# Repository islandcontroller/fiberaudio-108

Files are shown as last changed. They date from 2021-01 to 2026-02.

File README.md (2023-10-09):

# fiberaudio-108

[]()

A low-cost USB audio interface with S/PDIF optical output, based on the Cmedia CM108AH ASIC.

<p align="center"><picture>
  <source media="(prefers-color-scheme: dark)" srcset="doc/block-schem-wh.svg" />
  <source media="(prefers-color-scheme: light)" srcset="doc/block-schem.svg" />
  Block schematic
</picture></p>

View [**Schematic**](doc/sch_fiberaudio-108_rev5.pdf) :page_facing_up: or [**PCB Preview**](https://htmlpreview.github.io/?https://github.com/islandcontroller/fiberaudio-108/blob/master/doc/ibom.html) :globe_with_meridians:. Customize using the [**CM108AH Configuration Tool**](sw/README.md) :cd:.

Production files will be made available on the [Releases](https://github.com/islandcontroller/fiberaudio-108/releases) page, once validation is complete.

### Key features

* Cmedia CM108AH audio interface ASIC
* 2.0 Stereo, up to 16-bit/48kHz (CD-DA equivalent)
* USB Mini-B input
* Optical S/PDIF output (JIS F05, e.g. TOSLINK&trade;)
* USB Audio Device Class 1.0, uses generic drivers
* Configuration EEPROM

## Overview

This USB audio interface provides a low-cost S/PDIF optical output for portable computers and tablet devices. Audio tranmission via optical link - as opposed to a wired line-level connection - eliminates hum caused by ground potential differences, and noise feed-through from switched-mode power supplies.

| Design Requirement | Solution Approach |
|---|---|
| Provide electrical isolation between device and audio equipment | Audio signal transmission via optical link (e.g. TOSLINK&trade;) |
| Compatibility for wide range of operating systems, with minimal driver maintenance | USB Audio Device Class using OS-provided generic drivers |
| IP accessibility for PCB design files | Use of free, open-source EDA tooling (e.g. KiCad) |
| Commonly-used, small form-factor USB connector, robust enough to withstand portable use | USB **mini**-B receptacle |
| Option for manual assembly | Passives no smaller than 0603. ICs leaded and no smaller than 0.5mm pin pitch (SSOP) |
| Low PCB production capability requirements | &bullet;&nbsp;FR4 base material<br/>&bullet;&nbsp;2-layer Cu, Top+Bot Mask, Top Overlay<br/>&bullet;&nbsp;&geq;0.25mm trace-to-outline<br/>&bullet;&nbsp;&geq;0.25mm trace width and spacing<br/>&bullet;&nbsp;&geq;0.35mm drill size<br/>&bullet;&nbsp;Gerber, NC Drill and RS274X outputs |

## Design Review (Prototyping)

Prototyping was carried out using **rev. 3** board design files, in a minimum-order batch of 5 PCBs, including automated assembly.

### Assembly

* Manual rework of the PCB around `U3` (SRV05-4) was required in order to fix the issues found in *rev. 3*, after production was already started.
* Parts `U1` (AT93C46D), `U2` (CM108AH), `SW1`, and both connectors were unavailable for automated assembly, and had to be retrofitted manually using hot-air reflow soldering.

### Software Support

* Drivers included with **SteamOS 3.0** provide full functionality out-of-box, including volume controls for S/PDIF output.

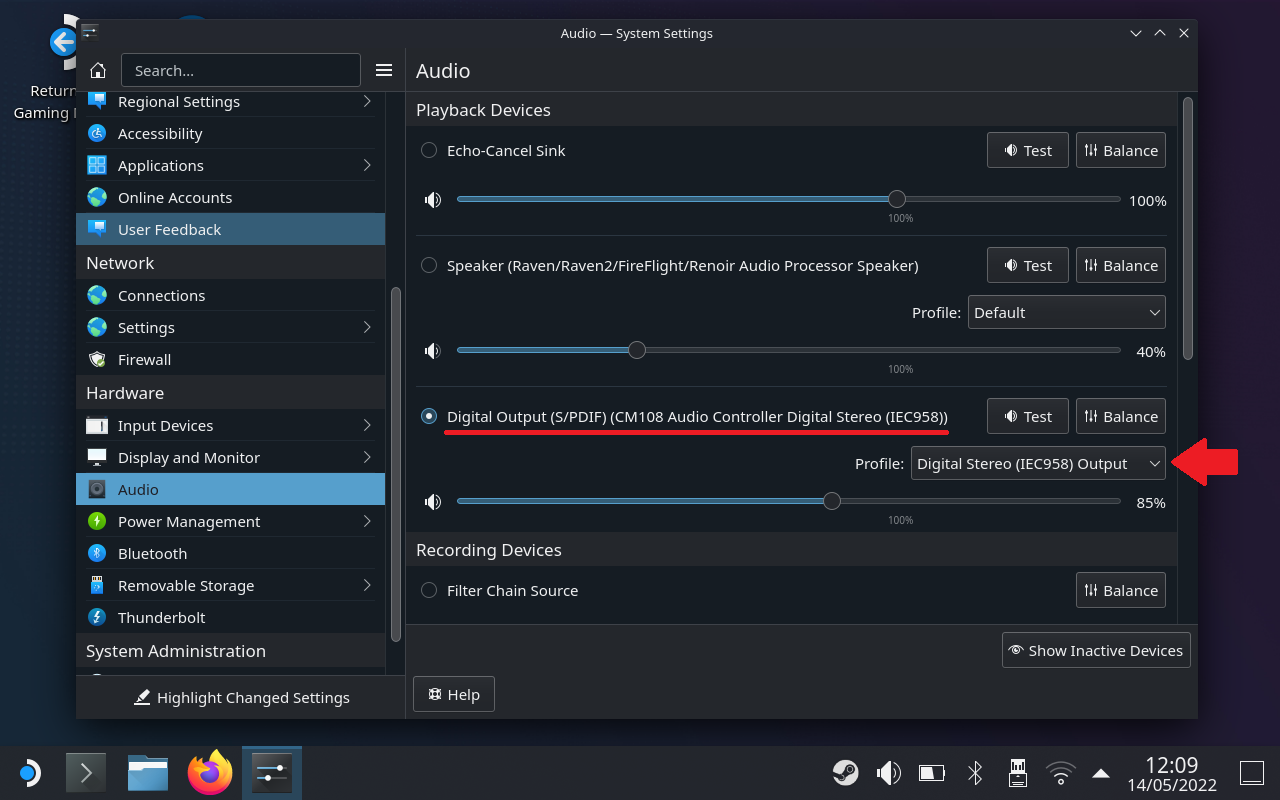
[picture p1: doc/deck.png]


* Generic Audio Device drivers included in **Windows 7.1** (x64) as well as **Windows 10** (Version 22H2, x64) only support S/PDIF output in a passthrough mode. **Volume control and the mute input are inoperative when using the default driver package** (see below for workaround).

**Workaround:** ~~A vendor-specific Windows driver package for the CM108AH is available for download from the ASIC manufacturer's website: [https://www.cmedia.com.tw/support/download_center](https://www.cmedia.com.tw/support/download_center).~~

> Updated 08/2023: *Unfortunately, the ASIC manufacturer have stopped providing any drivers for download. I uploaded the latest signed driver package I could source (Version 8.1.8.2172) as [release `v0.1.5-driver-only`](https://github.com/islandcontroller/fiberaudio-108/releases/tag/v0.1.5-driver-only). Please check the file for integrity and verify it includes the correct signed driver binary before installing.*

~~Using the Windows device manager, perform a manual driver update of the `Generic USB PnP Sound Device`, and select `Win8\SoftwareDriver` from the extracted archive as the driver installation sources directory.~~

> Updated 08/2023: *To install the driver, extract the archive and right-click install the `Cm108.INF` file.*

After installation and a reboot, a new `Digital Audio (USB PnP Sound Device)` device will show up in the Sound Settings dialog, alongside the old `Speakers (USB PnP Sound Device)` device. 

**Disable** the `Speaker` device.

This workaround was tested using Windows 7.1 (x64), and Windows 10 (Version 22H2, x64).

### Device Configuration

* A configuration tool for re-programming the external EEPROM was developed and is provided in the [`sw/`](sw/) subdirectory.

* EEPROM access sporadically seems to return invalid data. Re-reading or re-programming the affected words can be used as a workaround.

### Summary

* The device works correctly in connection with Linux systems. For Windows hosts, a custom driver installation is required for the device to operate properly.

## Licensing

If not stated otherwise within the specific file, the contents of this project are licensed under the CERN Open Hardware Licence Version 2 - Permissive. The full license text is provided in the [`LICENSE`](LICENSE) document.

        SPDX-License-Identifier: CERN-OHL-P-2.0

This licensing model is compliant with the [Open Source Hardware Definition 1.0](https://www.oshwa.org/definition/).

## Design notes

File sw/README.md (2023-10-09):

# CM108AH Configuration Tool

A Python tool for accessing the CM108AH external configuration EEPROM via the ASIC's custom HID endpoint.

## System requirements

* Python 3.8+
* Windows OS (limitation due to PyWinUSB.HID library)

## Installation

1. Create a new virtual environment using:

        python -m venv .venv

2. Activate the virtual environment

        .\.venv\Scripts\activate

3. Install the dependencies using the provided `requirements.txt` file:

        pip install -r requirements.txt

## Usage

Before running this tool, activate the Python virtual environment using:

    .\.venv\Scripts\activate

The tool uses a YAML configuration file to create and download an EEPROM image to the device. A blank configuration template is provided in [`config_template.yaml`](config_template.yaml). The proposed configuration for fiberaudio-108 boards is provided in [`fiberaudio-108.yaml`](fiberaudio-108.yaml).

To display a help message, use:

    python .\cm108ah.py -h

To list all available Cmedia devices, use: (**Note: Not all listed devices may support EEPROM features**)

    python .\cm108ah.py list

To program a configuration from an existing file into the device, use:

    python .\cm108ah.py program <filename>

Each mode command now supports fields for custom Vendor-ID, Product-ID and device index:

    python .\cm108ah.py read --vid 0d8c --pid 013c --device 1

**Retry programming, if the verification step fails.** After programming, the device needs to be power cycled, in order to apply the new configuration.

The tool offers additional options for erasing and reading the configuration EEPROM. See the help message for details.

## Licensing

This tool is part of the [fiberaudio-108](https://github.com/islandcontroller/fiberaudio-108) project. It is licensed under the parent project's conditions.

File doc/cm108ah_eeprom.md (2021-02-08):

# CM108AH EEPROM Access

The Cmedia `CM108` ASIC offers access to the attached EEPROM via an HID endpoint.
## Report data structure

Descriptions for each data byte of the in/out reports are provided in the [datasheet](cm108ah.pdf). For reference, the HID report number `0` needs to be prepended, for a total of 5 bytes per transfer.

## Read/Write access

Read/Write access modes are configured using the `HID_OR3 / EEPROM_CTRL` register. Command encoding differs from `AT93C46` access commands, as shown below.

| `EEPROM_CTRL` Bit | Descriptions |
|---|---|
| [7:6] | Access mode<br/>`0b10`: Read access<br/>`0b11`: Write access |
| [5:0] | Word address A<sub>5</sub>-A<sub>0</sub> |

**Read access mode** will initiate an SPI transfer to the external EEPROM, containing the `READ` command, followed by 16 clocks for the resulting output word.

    > SB (0x80 + addr)    0x00       0x00
    <                  data[15:8] data[7:0]

**Write access mode** will initially transfer an `EWEN` command to the EEPROM, followed by a `WRITE` transfer for 16 data bits. The CM108 will then toggle the clock line until the EEPROM signals a `READY` state.

    > SB 0x30  //  SB (0x40 + addr) data[15:8] data[7:0] 0x00 ... 0x00
    <                                                    BUSY ... READY

**Other access mode values** seem to have no effect, and do not produce any output on the SPI bus.

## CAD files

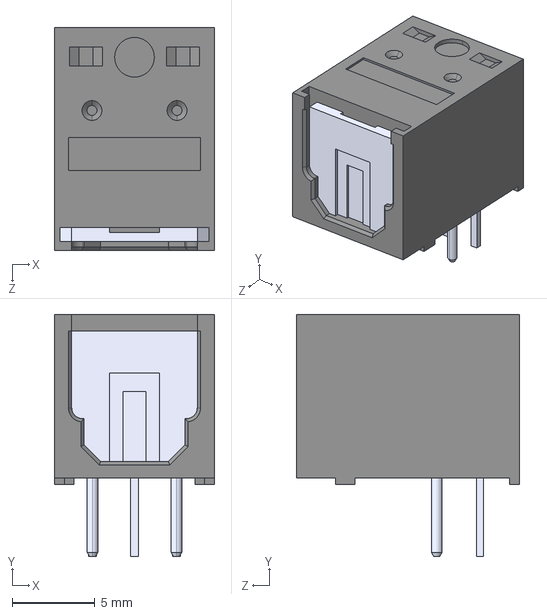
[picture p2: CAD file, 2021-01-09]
doc/plt133_t10w.step
9.70 x 14.7 x 13.5 mm

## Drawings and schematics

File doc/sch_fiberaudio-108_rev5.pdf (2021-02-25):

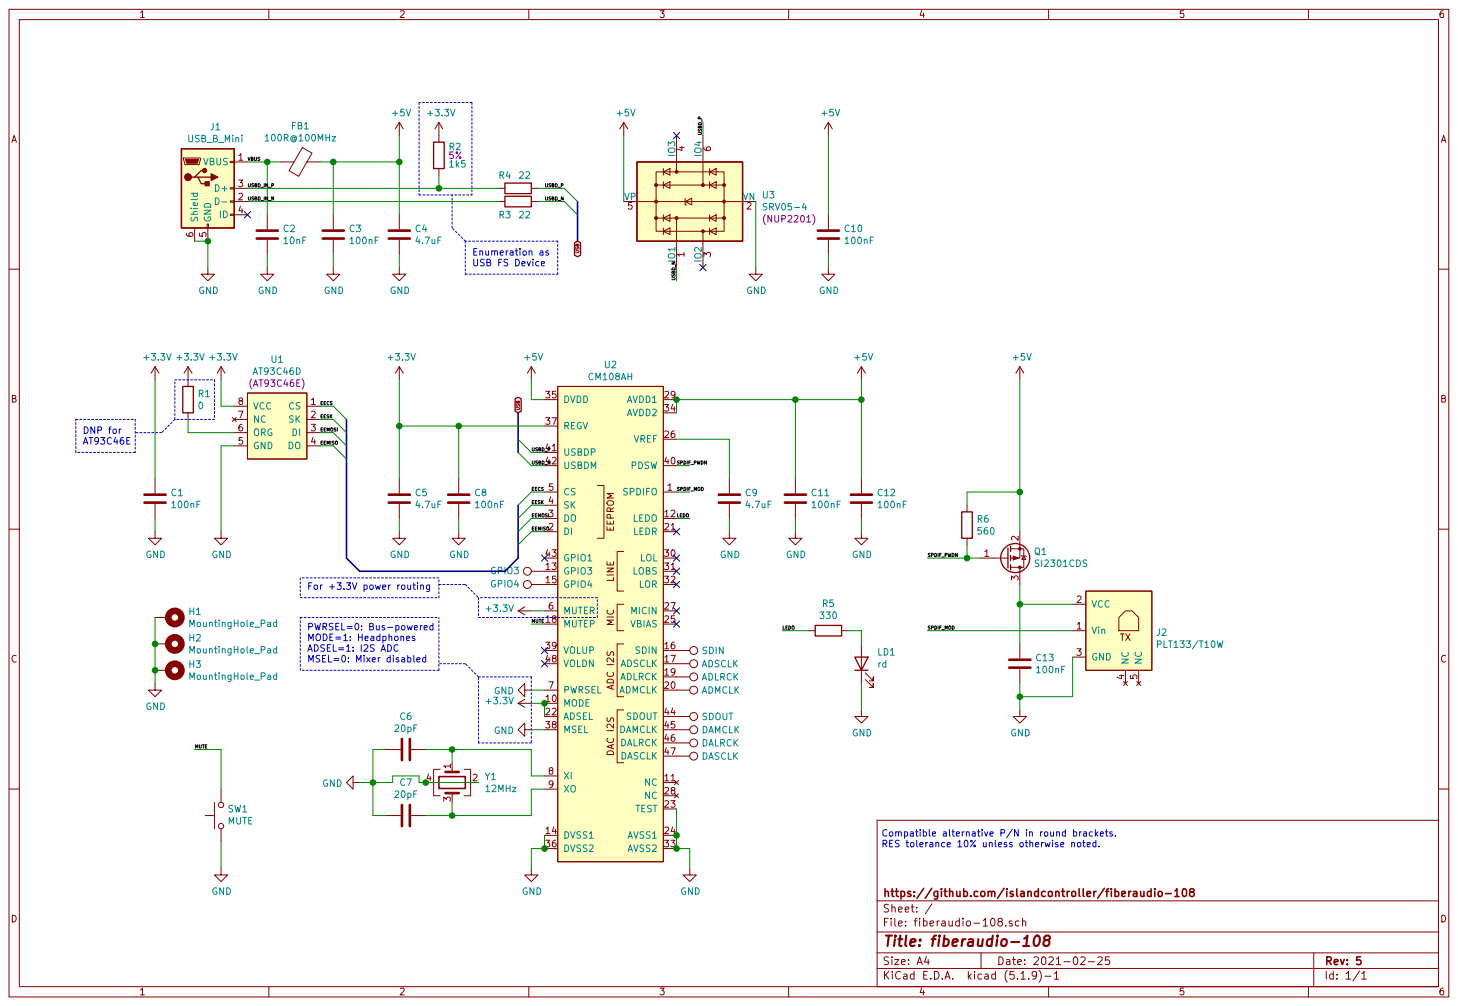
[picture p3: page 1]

MODE=1: Headphones ADSEL=1: I2S ADC MSEL=0: Mixer disabled For +3.3V power routing

File: fiberaudio-108.sch Sheet: / https://github.com/islandcontroller/fiberaudio-108

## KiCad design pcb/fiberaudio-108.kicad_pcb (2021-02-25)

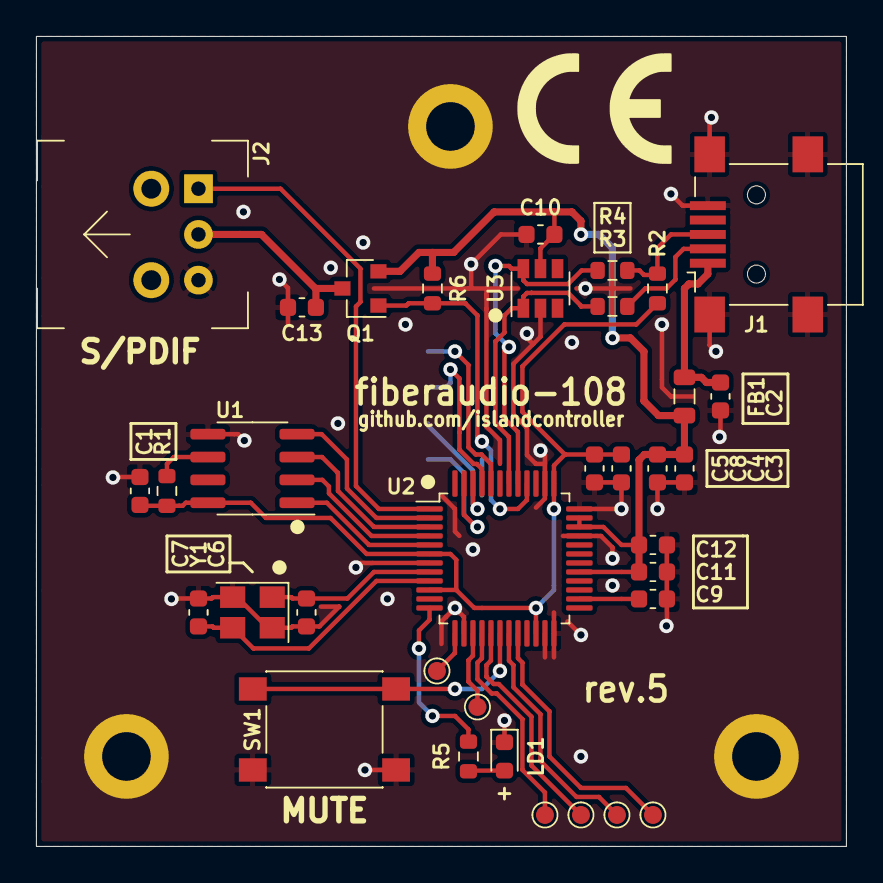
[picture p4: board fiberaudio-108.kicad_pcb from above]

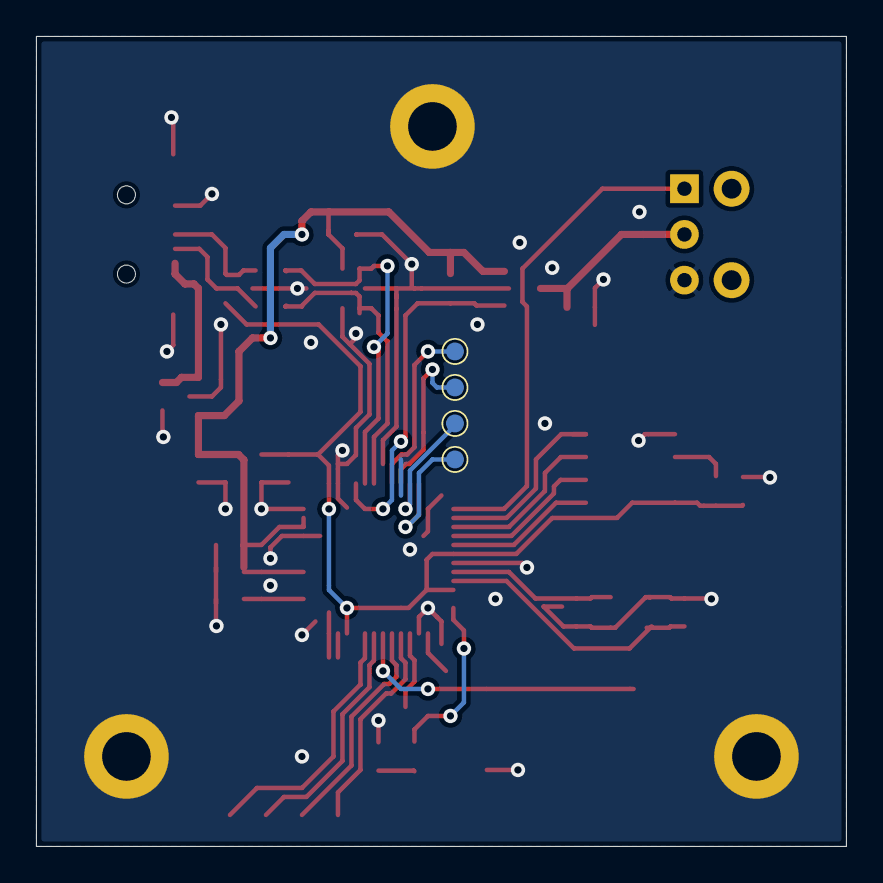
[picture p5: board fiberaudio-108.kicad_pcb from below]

Board: 2 copper layers, 45.0 x 45.0 mm, 42 parts (4 on the bottom side), 32 nets.

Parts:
C1, C3, C8, C10, C11, C12, C13: 100nF; C_0603_1608Metric
C2: 10nF; C_0603_1608Metric
C4, C5, C9: 4.7uF; C_0603_1608Metric
C6, C7: 20pF; C_0603_1608Metric
FB1: 100R@100MHz; L_0805_2012Metric
H1, H2, H3: MountingHole_Pad; MountingHole_2.7mm_M2.5_DIN965_Pad
J1: USB_B_Mini; USB_Mini-B_Lumberg_2486_01_Horizontal
J2: PLT133/T10W; PLT133_T10W
LD1: rd; LED_0603_1608Metric
Q1: SI2301CDS; SOT-23
R1: 0; R_0603_1608Metric
R2: 1k5; R_0603_1608Metric
R3, R4: 22; R_0603_1608Metric
R5: 330; R_0603_1608Metric
R6: 560; R_0603_1608Metric
SW1: MUTE; SW_SPST_PTS645
TP1: SDIN; TestPoint_Pad_D1.0mm
TP2: ADSCLK; TestPoint_Pad_D1.0mm
TP3: ADLRCK; TestPoint_Pad_D1.0mm
TP4: ADMCLK; TestPoint_Pad_D1.0mm
TP5: SDOUT; TestPoint_Pad_D1.0mm
TP6: DAMCLK; TestPoint_Pad_D1.0mm
TP7: DALRCK; TestPoint_Pad_D1.0mm
TP8: DASCLK; TestPoint_Pad_D1.0mm
TP9: GPIO3; TestPoint_Pad_D1.0mm
TP10: GPIO4; TestPoint_Pad_D1.0mm
U1: AT93C46D; SOIC-8_3.9x4.9mm_P1.27mm
U2: CM108AH; LQFP-48_7x7mm_P0.5mm
U3: SRV05-4; SOT-23-6
Y1: 12MHz; Crystal_SMD_3225-4Pin_3.2x2.5mm

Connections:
+3V3: C1.1, C5.1, C8.1, R1.1, R2.1, U1.8, U2.6, U2.10, U2.22, U2.37
+5V: C3.1, C4.1, C10.1, C11.1, C12.1, FB1.1, Q1.2, R6.1, U2.29, U2.34, U2.35, U3.5
/EECS: U1.1, U2.5
/EEMISO: U1.4, U2.2
/EEMOSI: U1.3, U2.3
/EESK: U1.2, U2.4
/LEDO: R5.2, U2.12
/MUTE: SW1.2, U2.18
/SPDIF_MOD: J2.1, U2.1
/SPDIF_PWDN: Q1.1, R6.2, U2.40
/USBD_IN_N: J1.2, R3.2
/USBD_IN_P: J1.3, R2.2, R4.2
/USBD_N: R3.1, U2.42, U3.1
/USBD_P: R4.1, U2.41, U3.6
/VBUS: C2.1, FB1.2, J1.1
GND: C1.2, C2.2, C3.2, C4.2, C5.2, C6.2, C7.2, C8.2, C9.2, C10.2, C11.2, C12.2, C13.2, H1.1, H2.1, H3.1, J1.5, J1.6, J2.3, LD1.1, SW1.1, U1.5, U2.7, U2.14, U2.23, U2.24, U2.33, U2.36, U2.38, U3.2, Y1.2, Y1.4
unnamed: C6.1, U2.8, Y1.1
unnamed: C7.1, U2.9, Y1.3
unnamed: C9.1, U2.26
unnamed: C13.1, J2.2, Q1.3
unnamed: LD1.2, R5.1
unnamed: R1.2, U1.6
unnamed: TP1.1, U2.16
unnamed: TP2.1, U2.17
unnamed: TP3.1, U2.19
unnamed: TP4.1, U2.20
unnamed: TP5.1, U2.44
unnamed: TP6.1, U2.45
unnamed: TP7.1, U2.46
unnamed: TP8.1, U2.47
unnamed: TP9.1, U2.13
unnamed: TP10.1, U2.15

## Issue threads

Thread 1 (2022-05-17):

"No devices found" when trying to read/program/erase.

siltemc, 2022-05-17:
Hi,

I am having trouble using your tool to program the EEPROM of a CM108B in windows.
I can not seem to find my USB audio device when using your script.
Example:
`python .\cm108ah.py erase`
`Entering ERASE mode.`
`No devices found.`

What can I do to resolve this?

I have confirmed operation of the device with a speaker and microphone in windows. As well as buttons/GPIO with an USB HID sniffer.

My understanding of the CM108B IC is that it is almost entirely the same as the CM108AH but with improved USB codec and internal crystal so your script should be able to talk to the EEPROM.

islandcontroller, 2022-05-17:
Hi there!

Thanks for the info on the codec and the crystal - I remember the differences were not too clear when designing the board.

Regarding the error message - I vaguely remember the `-B` variant using a different USB product ID than the `-AH`. I only have `-AH` chips on hand so I can't verify this myself unfortunately. If you know the correct one, the device filter can be modified in [`cm108ah.py#L27-L28`](https://github.com/islandcontroller/fiberaudio-108/blob/992eb214d844c5d7319f5c335846821c9f03a4d2/sw/cm108ah.py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)!

I'll put it on the ToDo to implement a `vid:pid` input and add the `-B` PID to the filter.

Let me know if this worked! :)

Closed 2023-10-09.

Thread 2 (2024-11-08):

Possibility to work with CM108B

monotech, 2024-11-08:
Hello. I am prototyping a project using CM108B, which is the chip currently available at electronics distributors.
It seems similar to its predecessors. The datasheet is almost the same, including the EEPROM section.

I can successfully read the EEPROM using your utility, but not write.

Also, I am probably missing something, but setting a product name longer than 16 characters is not allowed, but the datasheet says 30 characters, and I have CM108 device with a >16-character EEPROM-configured product name here.

Thanks!

islandcontroller, 2024-11-08:
Hi, thanks for raising this issue!

Regarding the 16 character limit - this indeed seems to be an error in the configuration processor, as the string descriptor contents are converted from ASCII to UTF-16LE by the CM108, internally. The correct limit is 31 characters for the manufacturer and product names (the "extra" character is stored in the same EEPROM word as the string length field).

Regarding write access to the EEPROM - it should be possible to write to the EEPROM using both -AH and -B parts. I did notice the tool now fails read-back when using the the driver version I re-published. As the memory contents get verified after programming anyway, I believe it is safe to remove the read-back verification/re-try part of the write operation.

I should be able to push fixes for both shortly.
Best regards!

monotech, 2024-11-09:
Awesome! That works fine, and I can now program the EEPROM on a CM108 and CM108B device.

Something else:
If I try to change the USB IDs, even after setting `enable_usb_ids: bool = True` on line 1139, I will get this warning and the USB IDs will be replaced with defaults:
`warnings.warn('Setting of USB IDs disabled - overriding with default (Cmedia CM108AH VID/PID)')`

islandcontroller, 2024-11-09:
Awesome, thanks for the feedback! :)

If you're using the command line tool for programming, use the `--enable-usb-ids 1` option to enable writing those bytes! The value you mentioned provides a default value for the `ConfgiurationReader` constructor, which in this case will get overridden by commandline arguments.

Note however, once you change the IDs, the tool won't detect the CM108 by default anymore. In that case, just add your custom IDs as commandline options with `--vid 0x.... --pid 0x....`.

semi-edit: ahh, ok! You got it to work before I could hit 'send' :D No worries!

Closed 2024-11-08.

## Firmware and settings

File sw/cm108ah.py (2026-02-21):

# Copyright 2021, islandcontroller_ and the fiberaudio-108 contributors
# SPDX-License-Identifier: CERN-OHL-P-2.0

# ------------------------------------------------------------------------------
# fiberaudio-108
# https://github.com/islandcontroller/fiberaudio-108
#
#   CM108AH Configuration Tool
#
# Copyright © 2021 islandcontroller_ and contributors
# Licensed under CERN Open Hardware Licence Version 2 - Permissive
#-------------------------------------------------------------------------------

import argparse
from enum import IntEnum
import hexdump
import pywinusb.hid as hid
import time
from typing import *
import warnings
import yaml

class Device:
    """CM108AH USB HID access controls
    """
    _MEMORY_SIZE_WORDS: int = 44
    _VENDOR_ID: int = 0x0D8C
    _PRODUCT_ID: int = 0x013C

    class Report:
        """Generic HID report
        """
        def __init__(self, report_num: int):
            """Instantiate generic HID report

            Args:
                report_num (int): Report number
            """
            self._report_num = report_num

        def get_data(self) -> List[int]:
            """Get raw generic HID report data

            Returns:
                List[int]: Raw HID report data
            """
            return [self._report_num]

    class OutReport(Report):
        """Generic CM108AH HID Out report
        """
        _ACCESS_EEPROM = 0x80
        _ACCESS_GPIO = 0x00

        class HidReg(IntEnum):
            """HID Out register definitions
            """
            HID_OR0 = 0
            HID_OR1 = 1
            HID_OR2 = 2
            HID_OR3 = 3

        def __init__(self, report_num: int):
            """Instantiate new HID Out report

            Args:
                report_num (int): HID report number (0)
            """
            super().__init__(report_num)
            self._regs = [0x00] * 4

        def set_reg(self, reg: HidReg, value: int):
            """Set register content

            Args:
                reg (HidReg): Register selector
                value (int): Register value (byte)

            Raises:
                ValueError: Register selector out of range
                ValueError: Register value out of range
            """
            if reg < 0 or reg > 3:
                raise ValueError('Invalid register selection')
            if value > 0xFF:
                raise ValueError('Value out of range')
            self._regs[reg] = value

        def get_reg(self, reg: HidReg) -> int:
            """Get register value

            Args:
                reg (HidReg): Register selector

            Raises:
                ValueError: Register selector out of range

            Returns:
                int: Register value
            """
            if reg < 0 or reg > 3:
                raise ValueError('Invalid register selection')
            return self._regs[reg]

        def get_data(self) -> List[int]:
            """Get raw HID Out report data

            Returns:
                List[int]: Raw HID Out report data
            """
            return [self._report_num] + self._regs

    class EepromOutReport(OutReport):
        """HID Out Report for EEPROM access
        """
        _EEPROM_READ = 0x80
        _EEPROM_WRITE = 0xC0
        _EEPROM_ADDR_MASK = 0x3F

        def __init__(self):
            """Instantiate new HID Out report
            """
            super().__init__(0)
            self.set_reg(self.HidReg.HID_OR0, self._ACCESS_EEPROM)

        def set_eeprom_ctrl(self, addr: int, write_access: bool):
            """Set control byte

            Args:
                addr (int): Word address
                write_access (bool): Select write access

            Raises:
                ValueError: EEPROM address out of range
            """
            if addr > self._EEPROM_ADDR_MASK:
                raise ValueError('Address out of range')
            access = self._EEPROM_WRITE if write_access else self._EEPROM_READ
            self.set_reg(self.HidReg.HID_OR3, access | addr)

        def set_eeprom_data16(self, value: int):
            """Set data from word

            Args:
                value (int): Data word

            Raises:
                ValueError: Value out of range
            """
            if value > 0xFFFF:
                raise ValueError('Value out of range')
            self.set_reg(self.HidReg.HID_OR2, (value >> 8) & 0xFF)
            self.set_reg(self.HidReg.HID_OR1, value & 0xFF)

        def set_eeprom_data8(self, value: List[int]):
            """Set data from list of bytes

            Args:
                value (List[int]): List of bytes (exactly 2)

            Raises:
                ValueError: List length does not match requirement
            """
            if len(value) != 2:
                raise ValueError('Value must be int[2] list with exactly 2 elements')
            self.set_reg(self.HidReg.HID_OR1, value[0])
            self.set_reg(self.HidReg.HID_OR2, value[1])

        def get_eeprom_data16(self) -> int:
            """Get data as word

            Returns:
                int: Data as word
            """
            return (self.get_reg(self.HidReg.HID_OR2) << 8) + self.get_reg(self.HidReg.HID_OR1)

        def get_eeprom_data8(self) -> List[int]:
            """Get data as list of bytes

            Returns:
                List[int]: Data as list of bytes
            """
            return [self.get_reg(self.HidReg.HID_OR1), self.get_reg(self.HidReg.HID_OR2)]

    class EepromReadOutReport(EepromOutReport):
        """HID Out report for data read access
        """
        def __init__(self, addr: int):
            """Instantiate new HID Out report

            Args:
                addr (int): Word address
            """
            super().__init__()
            self.set_eeprom_ctrl(addr, False)

    class EepromWrite16OutReport(EepromOutReport):
        """HID Out report for data word write access
        """
        def __init__(self, addr: int, value: int):
            """Instantiate new HID Out report

            Args:
                addr (int): Word address
                value (int): Data word
            """
            super().__init__()
            self.set_eeprom_ctrl(addr, True)
            self.set_eeprom_data16(value)

    class EepromWrite8OutReport(EepromOutReport):
        """HID Out report for 2 data bytes write access
        """
        def __init__(self, addr: int, value: List[int]):
            """Instantiate new HID Out report

            Args:
                addr (int): Word address
                value (List[int]): Data bytes (exactly 2)
            """
            super().__init__()
            self.set_eeprom_ctrl(addr, True)
            self.set_eeprom_data8(value)

    class GpioOutReport(OutReport):
        """HID Out report for GPIO and SPDIF access
        """
        def __init__(self):
            """Instantiate new GPIO access HID Out report
            """
            super().__init__(0)
            self.set_reg(self.HidReg.HID_OR0, self._ACCESS_GPIO)

        def set_spdif_status(self, valid: bool, data: int, category: int):
            """Set SPDIF status channel values

            Args:
                valid (bool): SPDIF status channel valid flag
                data (int): SPDIF status channel data nibble
                categoriy (int): SPDIF status channel category byte

            Raises:
                ValueError: Value for SPDIF status nibble out of range
                ValueError: Value for SPDIF category byte out of range
            """
            if data > 0x0F:
                raise ValueError('SPDIF status channel nibble out of range')
            if category > 0xFF:
                raise ValueError('SPDIF category byte out of range')
            self.set_reg(self.HidReg.HID_OR0, self._ACCESS_GPIO | data | (valid << 4))
            self.set_reg(self.HidReg.HID_OR3, category)

        def get_spdif_status_valid(self) -> bool:
            """Get SPDIF status channel valid flag from buffer

            Returns:
                bool: Status channel valid flag
            """
            return bool(self.get_reg(self.HidReg.HID_OR0) & 0x10)

        def get_spdif_status_data(self) -> int:
            """Get SPDIF status channel nibble from buffer

            Returns:
                int: SPDIF status channel nibble
            """
            return self.get_reg(self.HidReg.HID_OR0) & 0xF

        def get_spdif_status_cat(self) -> int:
            """Get SPDIF status channel category byte from buffer

            Returns:
                int: SPDIF status channel category byte
            """
            return self.get_reg(self.HidReg.HID_OR3)

        def set_gpio_data_reg(self, value: int):
            """Set GPIO data register

            Args:
                value (int): GPIO data register value (bit-masked output HIGH/LOW states)

            Raises:
                ValueError: GPIO data register value out of range
            """
            if value > 0x0F:
                raise ValueError('GPIO data value out of range')
            self.set_reg(self.HidReg.HID_OR1, value)

        def get_gpio_data_reg(self) -> int:
            """Get GPIO data register from buffer

            Returns:
                int: GPIO data register value
            """
            return self.get_reg(self.HidReg.HID_OR1)

        def set_gpio_dir_reg(self, value: int):
            """Set GPIO direction register value

            Args:
                value (int): GPIO direction register value (bit-masked out/in states)

            Raises:
                ValueError: GPIO direction register value out of range
            """
            if value > 0x0F:
                raise ValueError('GPIO direction value out of range')
            self.set_reg(self.HidReg.HID_OR2, value)

        def get_gpio_dir_reg(self) -> int:
            """Get GPIO direction register value from buffer

            Returns:
                int: GPIO direction register value
            """
            return self.get_reg(self.HidReg.HID_OR2)

    class InReport(Report):
        """Generic CM108AH HID In Report
        """
        class HidReg(IntEnum):
            """HID In register definitions
            """
            HID_IR0 = 0
            HID_IR1 = 1
            HID_IR2 = 2
            HID_IR3 = 3

        def __init__(self, data: List[int]):
            """Create new generic CM108 HID In report from raw data

            Args:
                data (List[int]): Raw HID In report data

            Raises:
                ValueError: Data does not match length requirements
            """
            if len(data) != 5:
                raise ValueError('Register list must contain exactly 5 items')

            report_num = data[0]
            regs = data[1:5]

            super().__init__(report_num)
            self._regs = regs

        def get_reg(self, reg: HidReg) -> int:
            """Get register value

            Args:
                reg (HidReg): Register selection

            Raises:
                ValueError: Register selector out of range

            Returns:
                int: Register value
            """
            if reg < 0 or reg > 3:
                raise ValueError('Invalid register selection')
            return self._regs[reg]

        def get_data(self) -> List[int]:
            """Get raw HID In report data

            Returns:
                List[int]: Raw HID In report data
            """
            return [self._report_num] + self._regs

    class EepromInReport(InReport):
        """HID In Report containing EEPROM data
        """
        def __init__(self, data: List[int]):
            """Instantiate EEPROM In Report from raw data

            Args:
                data (List[int]): Raw HID In report data
            """
            super().__init__(data)

        def get_eeprom_data16(self) -> int:
            """Get EEPROM data word

            Returns:
                int: EEPROM data word
            """
            return (self.get_reg(self.HidReg.HID_IR2) << 8) + self.get_reg(self.HidReg.HID_IR1)

        def get_eeprom_data8(self) -> List[int]:
            """Get EEPROM data as bytes list

            Returns:
                List[int]: EEPROM data fields as byte list
            """
            return [self.get_reg(self.HidReg.HID_IR1), self.get_reg(self.HidReg.HID_IR2)]

    class GpioInReport(InReport):
        """HID In report containing GPIO data
        """
        def __init__(self, data: List[int]):
            """Instantiate GPIO In report from raw data

            Args:
                data (List[int]): Raw HID In report data
            """
            super().__init__(data)

        def get_gpio_data_reg(self) -> int:
            """Get GPIO data register from buffer

            Returns:
                int: GPIO data register value
            """
            return self.get_reg(self.HidReg.HID_IR1)

        def get_gpio_buttons(self) -> int:
            """Get button states from buffer

            Returns:
                int: Button states
            """
            return self.get_reg(self.HidReg.HID_IR0) & 0xF

    class Button(IntEnum):
        """CM108 Button definitions
        """
        VOLUME_UP = 0x01
        VOLUME_DOWN = 0x02
        PLAY_MUTE = 0x04
        RECORD_MUTE = 0x08

    @classmethod
    def GetAvailableDevices(cls, vid: int = _VENDOR_ID, pid: int = None) -> List[hid.HidDevice]:
        """List all available devices matching VID/PID

        Args:
            vid: Vendor ID. Defaults to CMedia Vendor ID.
            pid: Product ID. Defaults to None (no filter).

        Returns:
            List[hid.HidDevice]: List of available HIDDevices matching VID/PID
        """
        if not pid: return hid.HidDeviceFilter(vendor_id=vid).get_devices()
        else:       return hid.HidDeviceFilter(vendor_id=vid, product_id=pid).get_devices()

    def __init__(self, device: hid.HidDevice):
        """Instantiate new CM108 Device handler from HIDDevice

        Args:
            device (hid.HidDevice): Underlying HIDDevice
        """
        self._hid_device: hid.HidDevice = device
        self._gpio_buttons: int = 0
        self._gpio_data: int = 0
        self._gpio_dir: int = 0

    def open(self):
        """Open underlying HID and assign HID in/out reports
        """
        self._hid_device.open()
        self._in_report = self._hid_device.find_input_reports()[0]
        self._out_report = self._hid_device.find_output_reports()[0]

    def read16(self, addr: int, num_words: int = 1, max_retry: int = 3) -> List[int]:
        """Read from EEPROM into list of words

        Args:
            addr (int): Start word address
            num_words (int, optional): Number of words to read. Defaults to 1.
            max_retry (int, optional): Maximum number of retries for each address. Must be greater than 0. Defaults to 3.

        Raises:
            IOError: Failed to send USB HID out report

        Returns:
            List[int]: EEPROM data as list of words
        """
        data = []
        for offset in range(0, num_words):
            last_read = []
            for n in range(0, max_retry + 1):
                # Generate and send USB HID out report
                read_out_report = self.EepromReadOutReport(addr + offset)
                self._out_report.set_raw_data(read_out_report.get_data())

                if not self._out_report.send():
                    raise IOError('Failed to send out report')

                # Readback data
                in_data = self._in_report.get()
                read_in_report = self.EepromInReport(in_data)

                # Garbage check
                read_data = [read_in_report.get_eeprom_data16()]
                if last_read == read_data:
                    # Data matches last read
                    data += read_data
                elif n < max_retry:
                    # Retry
                    last_read = read_data
                else:
                    # Number of re-tries exhausted
                    raise IOError(f"Failed to read consistent data at address 0x{addr + offset:04x}")
        return data

    def read8(self, addr: int, num_words: int = 1, max_retry: int = 3) -> List[int]:
        """Read from EERPOM into list of bytes

        Args:
            addr (int): Start word address
            num_words (int, optional): Number of **words** to read. Defaults to 1.
            max_retry (int, optional): Maximum number of retries for each address. Must be greater than 0. Defaults to 3.

        Raises:
            IOError: Failed to send USB HID Out report

        Returns:
            List[int]: EEPROM data as list of bytes
        """
        data = []
        for offset in range(0, num_words):
            last_read = []
            for n in range(0, max_retry + 1):
                # Generate and send USB HID out report
                read_out_report = self.EepromReadOutReport(addr + offset)
                self._out_report.set_raw_data(read_out_report.get_data())

                if not self._out_report.send():
                    raise IOError('Failed to send out report')

                # Readback data
                in_data = self._in_report.get()
                read_in_report = self.EepromInReport(in_data)

                # Garbage check
                read_data = read_in_report.get_eeprom_data8()
                if last_read == read_data:
                    # Data matches last read
                    data += read_data
                    break
                elif n < max_retry:
                    # Retry
                    last_read = read_data
                else:
                    # Number of re-tries exhausted
                    raise IOError(f"Failed to read consistent data at address 0x{addr + offset:04x}")
        return data

    def write16(self, addr: int, data: List[int]):
        """Write array of words to EEPROM

        Args:
            addr (int): Start word address
            data (List[int]): List of words

        Raises:
            IOError: Failed to send USB OUT report
            IOError: Repeated writes (retries) failed
        """
        for offset in range(0, len(data)):
            # Generate HID out report
            write_out_report = self.EepromWrite16OutReport(addr + offset, data[offset])
            self._out_report.set_raw_data(write_out_report.get_data())

            # Send HID Out report (optional retry)
            if not self._out_report.send():
                raise IOError('Failed to send out report')

    def write8(self, addr: int, data: List[int]):
        """Write array of bytes to EEPROM

        Args:
            addr (int): Start word address
            data (List[int]): List of bytes (multiple of 2!)

        Raises:
            ValueError: Length must be multiple of 2
            IOError: Failed to send USB HID out report
            IOError: Repeated writes (retries) failed
        """
        if len(data) & 0x1:
            raise ValueError('Data length must be multiple of 2')

        num_words = len(data) >> 1
        for offset in range(0, num_words):
            byte_offset = offset << 1

            # Generate HID Out report
            write_out_report = self.EepromWrite8OutReport(addr + offset, data[byte_offset:byte_offset+2])
            self._out_report.set_raw_data(write_out_report.get_data())

            # Send HID Out report (optional retry)
            if not self._out_report.send():
                raise IOError('Failed to send out report')

    def config_gpio(self, modes: int):
        """Configure GPIO in/out modes

        Args:
            modes (int): Output configuration

        Raises:
            ValueError: Configuration value out of range
        """
        if modes > 0x0F:
            raise ValueError('Modes value out of range')
        self._gpio_dir = modes
        self._update_gpio(self._gpio_data)

    def _update_gpio(self, data: int) -> int:
        """Send new GPIO states to the device and update inputs

        Args:
            data (int): New output states

        Raises:
            IOError: Failed to send HID report

        Returns:
            int: Updated input state buffer
        """
        # Generate HID Out report
        write_out_report = self.GpioOutReport()
        write_out_report.set_gpio_dir_reg(self._gpio_dir)
        write_out_report.set_gpio_dir_reg(data)
        self._out_report.set_raw_data(write_out_report.get_data())

        # Send report
        if not self._out_report.send():
            raise IOError('Failed to send out report')

        # Readback response
        in_data = self._in_report.get()
        write_in_report = self.GpioInReport(in_data)

        # Update internal buffers
        self._gpio_data = write_in_report.get_gpio_data_reg()
        self._gpio_buttons = write_in_report.get_gpio_buttons()
        return self._gpio_data

    def write_gpio_pin(self, pin: int, value: bool):
        """Write GPIO pin value

        Args:
            pin (int): GPIO pin number 1..4
            value (bool): Output state

        Raises:
            ValueError: GPIO pin selector out of range
        """
        if pin < 1 or pin > 4:
            raise ValueError('GPIO pin selection out of range')
        mask = 1 << (pin - 1)
        out_states = (self._gpio_data & ~mask) | (mask if value else 0)
        self._update_gpio(out_states)

    def write_gpio_reg(self, value: int):
        """Set GPIO data register value

        Args:
            value (int): Data register value

        Raises:
            ValueError: Register value out of range
        """
        if value > 0x0F:
            raise ValueError('GPIO data register value out of range')
        self._update_gpio(value)

    def read_gpio_pin(self, pin: int) -> bool:
        """Update cache and read pin signal state
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

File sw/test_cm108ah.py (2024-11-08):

# Copyright 2021, islandcontroller_ and the fiberaudio-108 contributors
# SPDX-License-Identifier: CERN-OHL-P-2.0

# ------------------------------------------------------------------------------
# fiberaudio-108
# https://github.com/islandcontroller/fiberaudio-108
#
#   Unit tests for the CM108AH Configuration Tool
#
# Copyright © 2021 islandcontroller_ and contributors
# Licensed under CERN Open Hardware Licence Version 2 - Permissive
#-------------------------------------------------------------------------------

from cm108ah import *
import unittest

class TestReport(unittest.TestCase):
    def test_GetData(self):
        expect_report_num = 1
        expect_data = [expect_report_num]

        r = Device.Report(expect_report_num)
        self.assertListEqual(r.get_data(), expect_data)

class TestOutReport(unittest.TestCase):
    def test_GetData(self):
        expect_report_num = 1
        expect_data_len = 5
        expect_data = [expect_report_num, 0, 0, 0, 0]

        r = Device.OutReport(expect_report_num)
        self.assertEqual(len(r.get_data()), expect_data_len)
        self.assertListEqual(r.get_data(), expect_data)

    def test_Regs(self):
        expect_hid_or0 = 0
        expect_hid_or1 = 1
        expect_hid_or2 = 2
        expect_hid_or3 = 3

        actual_hid_or0 = Device.OutReport.HidReg.HID_OR0
        actual_hid_or1 = Device.OutReport.HidReg.HID_OR1
        actual_hid_or2 = Device.OutReport.HidReg.HID_OR2
        actual_hid_or3 = Device.OutReport.HidReg.HID_OR3

        self.assertEqual(actual_hid_or0, expect_hid_or0)
        self.assertEqual(actual_hid_or1, expect_hid_or1)
        self.assertEqual(actual_hid_or2, expect_hid_or2)
        self.assertEqual(actual_hid_or3, expect_hid_or3) 

    def test_SetRegValueRange(self):
        expect_pass_value = 0xFF
        expect_fail_value = 0x100

        r = Device.OutReport(0)

        try:
            r.set_reg(Device.OutReport.HidReg.HID_OR0, expect_pass_value)
            r.set_reg(Device.OutReport.HidReg.HID_OR1, expect_pass_value)
            r.set_reg(Device.OutReport.HidReg.HID_OR2, expect_pass_value)
            r.set_reg(Device.OutReport.HidReg.HID_OR3, expect_pass_value)
        except:
            self.fail()

        self.assertRaises(ValueError, r.set_reg, Device.OutReport.HidReg.HID_OR0, expect_fail_value)
        self.assertRaises(ValueError, r.set_reg, Device.OutReport.HidReg.HID_OR1, expect_fail_value)
        self.assertRaises(ValueError, r.set_reg, Device.OutReport.HidReg.HID_OR2, expect_fail_value)
        self.assertRaises(ValueError, r.set_reg, Device.OutReport.HidReg.HID_OR3, expect_fail_value)

    def test_SetRegSelectRange(self):
        expect_pass_value = 3
        expect_fail_value1 = -1
        expect_fail_value2 = 4

        r = Device.OutReport(0)

        try:
            r.set_reg(expect_pass_value, 0)
        except:
            self.fail()

        self.assertRaises(ValueError, r.set_reg, expect_fail_value1, 0)
        self.assertRaises(ValueError, r.set_reg, expect_fail_value2, 0)

    def test_SetRegValuePosition(self):
        reg_select_enum = [
            Device.OutReport.HidReg.HID_OR0,
            Device.OutReport.HidReg.HID_OR1,
            Device.OutReport.HidReg.HID_OR2,
            Device.OutReport.HidReg.HID_OR3
        ]
        reg_select_int = [0, 1, 2, 3]
        reg_value = [1, 2, 3, 4]
        reg_data = [
            [0, 1, 0, 0, 0],
            [0, 0, 2, 0, 0],
            [0, 0, 0, 3, 0],
            [0, 0, 0, 0, 4]
        ]
        
        for i in range(0, 4):
            select_enum = reg_select_enum[i]
            select_int = reg_select_int[i]
            value = reg_value[i]
            expect_data = reg_data[i]

            r_enum = Device.OutReport(0)
            r_enum.set_reg(select_enum, value)
            r_int = Device.OutReport(0)
            r_int.set_reg(select_int, value)
            
            self.assertListEqual(r_enum.get_data(), expect_data)
            self.assertListEqual(r_int.get_data(), expect_data)

    def test_SetRegMultiple(self):
        values = [1, 2, 3, 4]
        expect_data = [0, 1, 2, 3, 4]

        r = Device.OutReport(0)
        for i in range(0, 4):
            r.set_reg(i, values[i])

        self.assertListEqual(r.get_data(), expect_data)

    def test_GetRegSingle(self):
        select_enum = [
            Device.OutReport.HidReg.HID_OR0,
            Device.OutReport.HidReg.HID_OR1,
            Device.OutReport.HidReg.HID_OR2,
            Device.OutReport.HidReg.HID_OR3,
        ]
        expect_values = [1, 2, 3, 4]

        for i in range(0, 4):
            r = Device.OutReport(0)
            r.set_reg(i, expect_values[i])
            
            self.assertEqual(r.get_reg(select_enum[i]), expect_values[i])
            self.assertEqual(r.get_reg(i), expect_values[i])

    def test_GetRegMultiple(self):
        select_enum = [
            Device.OutReport.HidReg.HID_OR0,
            Device.OutReport.HidReg.HID_OR1,
            Device.OutReport.HidReg.HID_OR2,
            Device.OutReport.HidReg.HID_OR3,
        ]
        expect_values = [1, 2, 3, 4]

        r = Device.OutReport(0)
        for i in range(0, 4):
            r.set_reg(i, expect_values[i])

        for k in range(0, 4):
            self.assertEqual(r.get_reg(select_enum[k]), expect_values[k])
            self.assertEqual(r.get_reg(k), expect_values[k])
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

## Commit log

2021-01-09 Add initial PCB files
    [fiberaudio-108.kicad_pcb, fiberaudio-108.sch]
2021-01-09 Add schematic, custom components and initial layout
    [fiberaudio-108.kicad_pcb, fiberaudio-108.sch, plt133_t10w.step]
2021-01-09 Add schematic print
2021-01-09 Fix typo in schematic
    [fiberaudio-108.sch]
2021-01-09 Add initial routed layout
    [fiberaudio-108.kicad_pcb, fiberaudio-108.sch]
2021-01-10 Redesign for automated assembly
    [fiberaudio-108.kicad_pcb, fiberaudio-108.sch]
2021-01-10 Added testpoints; Removed erroneous file
    [fiberaudio-108.kicad_pcb, fiberaudio-108.sch]
2021-01-10 Updated schematic to rev3
    [fiberaudio-108.sch]
2021-01-10 Adjust thermal relief to help prevent tombstoning
    [fiberaudio-108.kicad_pcb]
2021-01-11 Adjust PCB page layout for print
    [fiberaudio-108.kicad_pcb]
2021-01-12 Fix USBD disco at U3; Adjust VBUS/+5 routing; Update to rev.4
    [fiberaudio-108.kicad_pcb, fiberaudio-108.sch]
2021-01-15 Fix USB connector type in README; Add information about audio data rate
2021-01-22 Replace clamp diode array DS; Add XTAL datasheet
2021-02-06 Fix list type hints for Python 3.8
    [cm108ah.py]
2021-02-25 Add alternative P/Ns, RES tolerance values
    [fiberaudio-108.sch]
2021-02-25 Rev. 5; Add ALTN part for ESD diode; Adjust layout
    [fiberaudio-108.kicad_pcb, fiberaudio-108.sch]
2021-02-26 Add button state readout to config tool
2021-02-26 Add PCB preview
2023-08-25 Add driver package notice; Update latest tested Windows OS version
2023-08-25 Add dark-mode block schematic
2023-10-09 Resolve #1: Expand device search to cover all Cmedia devices by default; Add cmdline fields for custom VID and PID
    [cm108ah.py]
2023-10-09 Add note regarding possibly unsupported devices in listing
2024-11-08 Fix incorrect manufacturer and product name length limits
    [cm108ah.py, test_cm108ah.py]
2026-02-21 Add automatic white-space trimming; Fix cm108ah.py formatting
    [cm108ah.py]
